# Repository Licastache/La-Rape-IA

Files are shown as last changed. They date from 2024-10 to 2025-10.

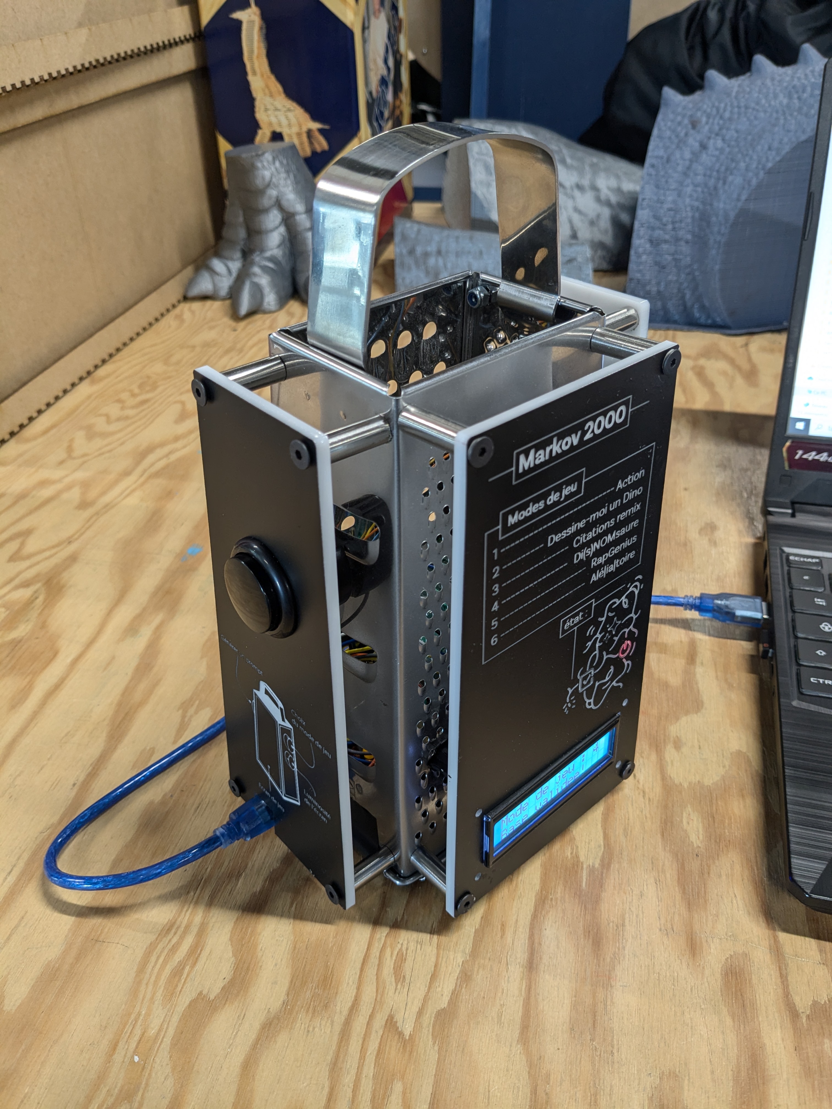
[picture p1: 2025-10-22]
Photos pour git/PXL_20241113_132945148.jpg

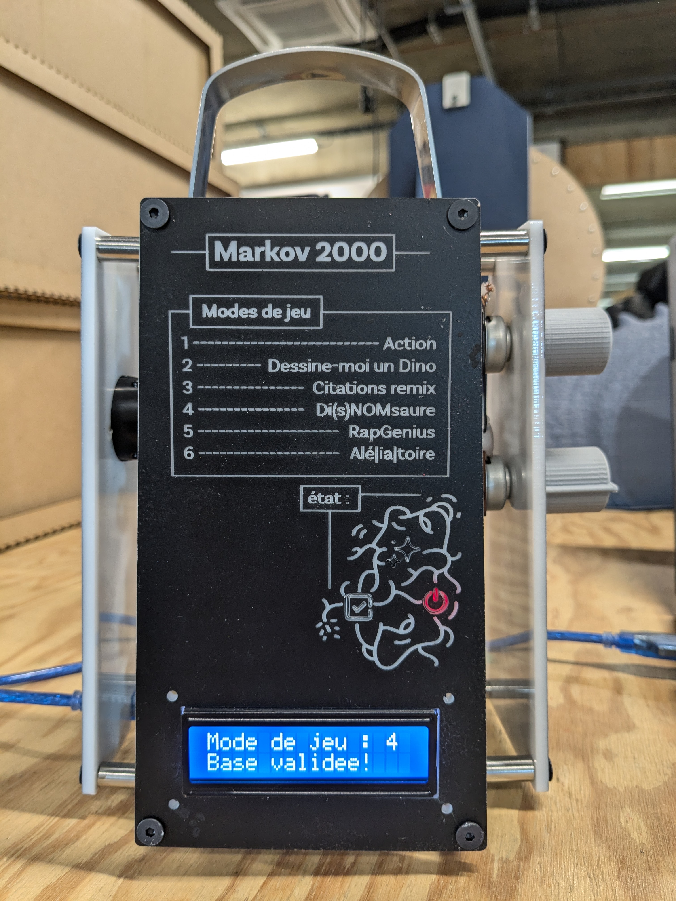
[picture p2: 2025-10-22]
Photos pour git/PXL_20241113_132952643.jpg

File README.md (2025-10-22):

Bienvenue au tutoriel du fonctionnement de la râpe IA Markov 2000 ! 

Informations importantes : 

- 1 : ce projet est une réinterprétation du projet "Trouble Maker" de @liangyq404 :

- 2 : Ce README n'est pas encore tout à fait à jour. Nous conseillons au lecteur de faire attention à l'étape de configuration de l'ordinateur (dans l'étape 3), qui est issue de la première contribution de @VianneyDubourg, avant la mise à jour du code de @nopalpite et l'intégration dans le raspberry pi à la place de l'ordinateur

https://github.com/liangyq404/trouble_maker

https://yibo-fu.com/TroubleMaker

Pour commencer, nous allons parler de la fabrication de la râpe. Ensuite, nous verrons comment préparer et contrôler l'ordinateur et, pour finir, je vous montrerai comment la faire fonctionner.  

Matériel nécessaire  

Avant de commencer, voici la liste du matériel dont vous aurez besoin pour créer une râpe Markov 2000 fonctionnelle :  

- 1 fer à souder à l’étain pour les brasures  
- 1 bobine d’étain  
- 1 kit de jumpers Arduino (mâle-femelle et mâle-mâle)  
- 1 bouton de borne d’arcade  
- 2 potentiomètres compatibles Arduino  
- 1 écran bleu à cristaux liquides sans I2C  
- 1 râpe à fromage  
- 1 imprimante 3D  
- 1 découpeuse laser  
- 12 boulons et écrous M3x30  
- 1 plaque de plexiglas blanc de 4 mm (50x80 cm)  
- 1 bombe de peinture acrylique mate noire  
- 1 tube en acier de 5 mm de diamètre intérieur
- 1 raspberry pi

---

ÉTAPE 1 : Préparer et souder tous les éléments  

IA QUOI LA DEDANS _ (1)

⚠ ATTENTION ! Ne soudez pas encore le bouton et les potentiomètres, car les câbles doivent d'abord passer dans les trous de la râpe.  

---

ÉTAPE 2 : Découpe laser du carénage  

Pour cette étape, nous allons utiliser une découpeuse laser. Prenez votre plaque de PMMA de 4 mm (ou trolase noir/blanc) et lancez la découpe du fichier "Plaque de trolase habillage rape v3.SVG".  

---

ÉTAPE 3 : Assemblage

1. Découpez votre tube en acier de 5 mm en tronçons de 20 mm.  
2. Fixez les plaques sur la râpe (pensez à percer tous les trous nécessaires au préalable).  
3. Utilisez les boulons et écrous M3x30 pour fixer le carénage.  

---
------------  ETAPE A CORRIGER -----------------
Ensuite, nous allons voir comment configurer l'ordinateur.  

Logiciels requis  

Pour commencer, vous devez installer trois logiciels sur votre ordinateur :  

- **Arduino IDE**  
- **VS Code** de Microsoft  
- **Python 3** (version minimale requise) – Téléchargeable sur : [https://www.python.org/](https://www.python.org)  

⚠ **ATTENTION !** Lors de l’installation de Python, assurez vous de bien l’ajouter au **PATH**.

---

Après cela, ajoutez le dossier **TM-SCREEN** sur le bureau de votre ordinateur.  

### **Ouverture du projet dans VS Code**  

1. Ouvrez **VS Code**.  
2. Cliquez sur **Fichier > Ouvrir un dossier** (**File > Open Folder**).  
3. Sélectionnez le dossier **TM-SCREEN**.  

Cela chargera l’ensemble du dossier dans l’onglet de gauche.  

4. Ouvrez le fichier **Python** contenu dans le dossier.  
5. VS Code devrait normalement vous demander d’installer l’extension **Python** sur votre ordinateur. Installez-la si ce n’est pas déjà fait.  

302d3364e0134f43e909c34b77ef948b

---

## **ÉTAPE 4 : Création de la variable d'environnement Python**  

Ensuite, vous devez associer la variable d’environnement disponible dans le fichier **.env** avec le fichier **requirements.txt**.  

---

## **ÉTAPE 5 : Vous pouvez râper des mots** 🧀💻

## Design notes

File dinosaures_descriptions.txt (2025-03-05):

Prédateur redoutable, il mesurait 12 mètres et pesait 9 tonnes.
Carnivore agile, rapide et intelligent, avec des griffes acérées.
Herbivore géant, au long cou, se nourrissant de feuillage élevé.
Herbivore cornu, doté de trois cornes pour se défendre.
Dinosaure à plaques, avec un dos orné et une queue pointue.
Armure vivante, possédant une queue-massue défensive.
Crête osseuse distinctive, utilisée pour la communication.
Vol majestueux, envergure de 7 mètres, chasseur aérien de poissons.
Prédateur bipède, 9 mètres de long, dents tranchantes et griffes acérées.
Herbivore immense, 27 mètres, mangeant les feuilles des arbres.
Prédateur à griffes, rapide et agile pour chasser efficacement.
Herbivore blindé, protégé par une carapace de plaques osseuses.
Chasseur furtif, petit, rapide et précis dans ses attaques.
Géant des airs, plane sur de longues distances en quête de nourriture.
Roi des mers, prédateur marin dominant avec des dents acérées.
Dinosaure à cornes, armes naturelles pour défense et domination.
Dinosaure à bec, adapté à la chasse avec un bec puissant.
Marcheur des marécages, se nourrissant de plantes aquatiques.
Chercheur de trésors, fouille le sol avec ses longues griffes.
Géant des forêts, avancée lente à travers la végétation dense.
Grand bipède carnivore, bras courts, dents acérées, du Crétacé supérieur.
Herbivore massif, long cou et queue, vivait au Jurassique.
Herbivore cornu, collerette osseuse, trois cornes, du Crétacé tardif.
Petit chasseur bipède, griffe en faucille, rapide et agile.
Herbivore blindé, plaques osseuses et queue défensive.
Prédateur à voile dorsale, grand chasseur du Crétacé inférieur.
Dinosaure bipède à plumes, entre dinosaures et oiseaux.
Herbivore à dôme crânien, structure osseuse pour protection.
Herbivore bipède, crête creuse servant à la communication.
Herbivore quadrupède, queue défensive couverte de pointes.
Carnivore à longues griffes, tête petite, du Crétacé supérieur.
Quadrupède massif, peau épaisse, protégé par de petites épines.
Crête osseuse imposante, pour intimider ou séduire.
Petit bipède omnivore, rapide, au bec tranchant.
Quadrupède blindé, plaques osseuses et épines défensives.
Carnivore à museau fin et dents acérées.
Herbivore bipède, bec corné, crête denteleuse sur le dos.
Dinosaure à plumes, ailes rudimentaires, proche des oiseaux.
Quadrupède géant, queue en massue pour se défendre.
Carnivore bipède, crête osseuse pour combat territorial.
Herbivore blindé, plaques osseuses et queue pointue.
Carnivore bipède, tête massive, dents tranchantes, redoutable prédateur.
Herbivore géant, long cou et pattes robustes.
Bipède carnivore, griffes acérées, queue robuste pour l’équilibre.
Herbivore blindé, longues épines dorsales, thermorégulation.
Carnivore bipède, dents tranchantes et museau allongé.
Herbivore bipède, bec puissant et crêtes osseuses.
Dinosaure bipède, plumes, griffes acérées, lien vers les oiseaux.
Herbivore quadrupède, collerette osseuse et cornes frontales.
Carnivore bipède, crête creuse, queue longue et agile.

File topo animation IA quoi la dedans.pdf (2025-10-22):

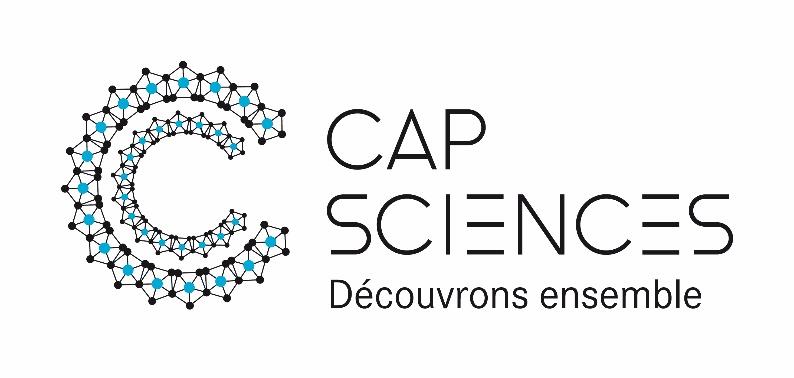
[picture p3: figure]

Fab Lab – Format 1H | Atelier Découverte

# IA quoi là-dedans ?

# Fab Lab

# Format 1H30

Généralités :

- 16 participants
- A partir de 12 ans (5ème)
- 1h30 d’activité
- Montage : 30 min
- Démontage : 30 min

Matériel :

- 3 trouble maker assemblés
- 3 trouble maker éclatés (dans les boites en carton)
- 3 mousses plastazotes
- 3 raspberry pi
- 1 ordinateur diaporama
- 1 clé USB contenant le diaporama
- 3 jeux de cartes composants
- 16 ardoises et crayons d’ardoise
- 1 sac/boite contenant des cartes phrases
- 1 boite à pixels

### Résumé :

Cet atelier se déroule en 1h30.

### Installation :

Former trois îlots pouvant accueillir 5 personnes chacun. Placer un Trouble Maker fonctionnel sur chacun d’eux. Des gommettes sur les PC et râpes permettent d’identifier

Brancher le trouble maker sur le raspberry pi et le disposer au centre de la table.

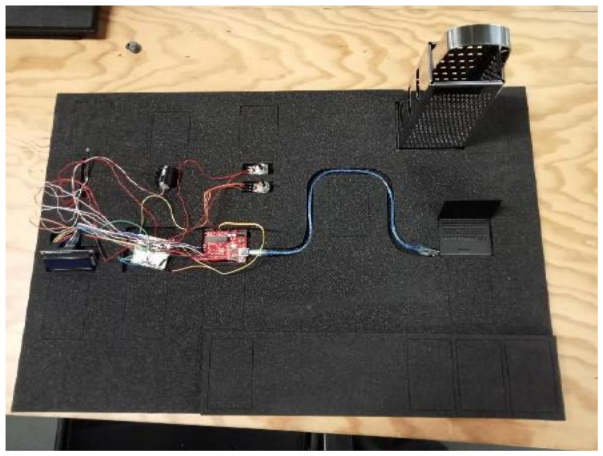
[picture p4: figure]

Disposer les composants des éclatés dans les mousses et mettre le tout de côté.

Mettre de côté les jeux de Memory, les phrases, le cadavre exquis et les ardoises.

Ouvrir le diapo IA quoi la dedans.

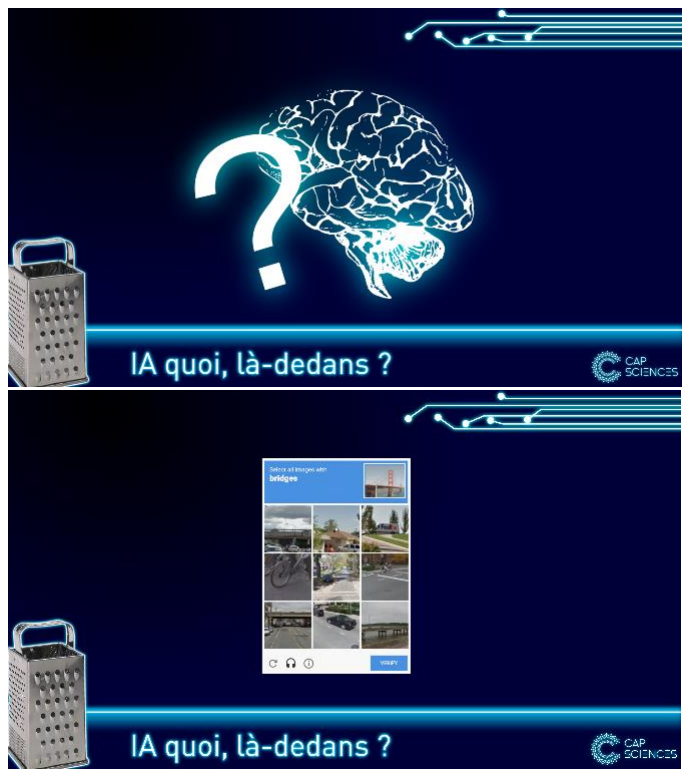
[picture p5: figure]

## Déroulé détaillé :

### 1ère Partie : Découverte du Trouble Maker // 20 minutes

Après s’être présentée et avoir fait connaissance avec les participants, l’animatrice explique :

Avant de débuter, je dois juste vérifier que vous êtes bien des humains. C’est la procédure.

Elle affiche les deux démos du ReCAPTCHA qui sont dans le diapo.

Très bien, pouvez-vous me dire où se trouvent les passages piétons ? Les vélos ? Super, merci beaucoup, on peut continuer.

L’animatrice explique alors aux participants le but de l’atelier : comprendre ce qu’est l’objet qu’ils ont devant eux, ce qu’il y a à l’intérieur et comment il fonctionne.

La première étape est donc de laisser les groupes manipuler l’objet sans leur donner d’instructions. Après 5 minutes, on peut récupérer l’attention de tout le groupe et enchaîner.

Est-ce que vous avez compris ce que fait cet objet ? Pouvez-vous me l’expliquer en quelques phrases ?

A la fin de cette séquence, les participants doivent avoir compris qu’on peut choisir un mode de fonctionnement, et que lorsqu’on appuie sur le gros bouton, cela génère une phrase liée au mode.

L’animatrice demande ensuite si les participants peuvent citer les différents composants de l’objet ainsi que ce à quoi ils servent. Afin de mieux voir, elle apporte un éclaté par groupe et leur donne les cartes composants. Ils peuvent disposer les cartes à côté de chaque composant.

Elle leur demande ensuite de résumer ce que font les différentes parties et apporte la correction si besoin.

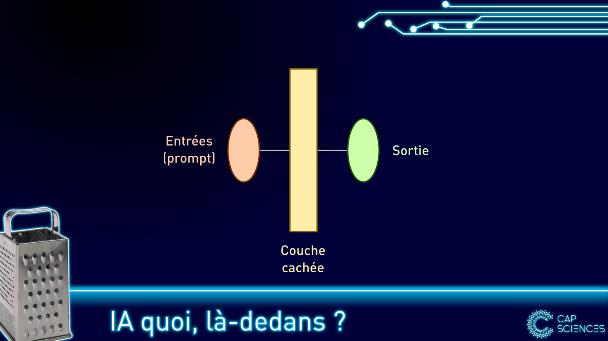
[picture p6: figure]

2

### ème partie : Dans le cerveau de la machine

On sait comment ça fonctionne physiquement ; maintenant on va voir comment ça fonctionne en terme de programmation.

Cette machine ressemble un peu à ChatGPT, Copilot et autres. Elle génère du texte. Comment ? Vous tapez une commande (votre prompt), puis la machine fait quelque chose (on ne sait pas quoi) et vous avez un résultat en sortie. Mettez le Trouble Maker en position Alé(IA)toire et faites-moi sortir une phrase.

Qu’est ce qui sort ? Est-ce que c’est compréhensible ?

Je vais vous donner un papier et j’aimerais que vous me disiez si ça vous permet de comprendre ce que fait la machine.

L’animatrice donne alors la base de données en version papier, ou affiche la base de données sur l’ordinateur du groupe. La réponse attendue est que la machine imprime une phrase composée de blocs pris parmi la liste. Cette liste est une base de données, c’est-à-dire un conteneur qui permet de stocker des données (une liste de noms, de numéros de téléphone, de recettes, etc).

La machine est, entre guillemets, « créative » et afin d‘éviter le temps pris pour générer une quinzaine de phrases, l’animatrice place la Boîte à phrases au centre de la pièce.

Vous allez tous venir piocher une phrase dans cette boite. On va les lire à voix haute et se placer dans d’un côté de la pièce si on estime que la phrase est correcte, et de l’autre si on estime que la phrase est incorrecte.

Les participants s’exécutent et l’animatrice demandent à ceux qui se placent côté incorrect, pourquoi ils estiment leur phrase fausse.

Elle propose ensuite de comprendre comment Trouble Maker construit ses phrases. On lui a appris qu’une phrase commence par une majuscule, se termine par un point, mais on ne lui a pas appris ce qu’est un nom, une action, un lieu ou un objet. Le Trouble Maker se débrouille pour prédire le prochain mot selon une logique qu’on va essayer d’appréhender.

Les participants prennent une ardoise chacun et, par petits groupes, vont noter sans regarder ce que font les autres :

- Le premier : un nom (Dingo, Mon parrain, Un oreiller, Sélim…)
- Le deuxième : une action (se tient, déclare un poème, épluche, est posé…)
- Le troisième : un lieu (à la piscine, chez mamie Monique, dehors…)
- Le quatrième : un objet précédé par « avec » (avec un chou, avec une épée, avec un origami…)
- Le cinquième une date (demain, le 30 février, il y a très longtemps…)

La phrase finale est ensuite lue dans son intégralité. On constate qu’elle est largement insensée. La question peut alors être posée :

Comment peut-on améliorer ce processus ?

Plusieurs réponses peuvent être apportées par les jeunes. Celle qui nous intéresse est la suivante : savoir ce qui a été écrit auparavant.

On peut donc recommencer l’exercice en intégrant ce paramètre. La base de donnée sera nos connaissances à nous, êtres humains, et avant d’écrire notre mot, on peut regarder le mot écrit par la personne avant nous. A la fin de la séquence, récupérer les ardoises en crayons.

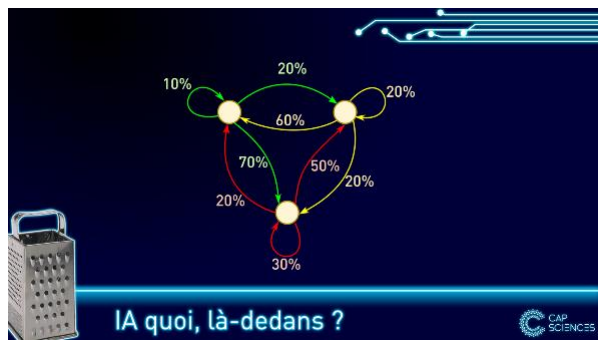
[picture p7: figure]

Ce que nous venons de faire, à quoi est-ce que ça ressemble ? A la prédiction automatique de notre téléphone, exactement ! Eh bien nous venons de recréer un modèle de langage : une chaine de Markov.
C’est un processus dont l’évolution future ne dépend que de la situation présente.

Exemple : si, quand je suis dans ce coin de la pièce, j’ai 1 chance sur 3 d’aller dans le coin à ma droite et 2 chances sur 3 d’aller dans le coin à ma gauche, savoir comment je suis arrivé dans ce coin n’aura aucune incidence sur le choix de l’endroit où je vais aller.

Bien s’assurer que ce processus est compris par l’assemblée. Leur demander de réexpliquer au besoin.

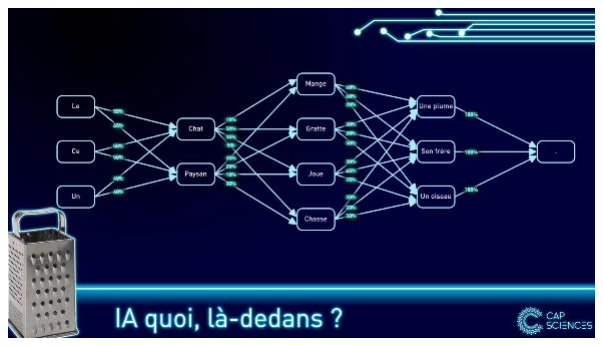
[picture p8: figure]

Pour nos phrases, c’est pareil : Markov utilise le mot actuel pour choisir le mot suivant. Pour cela, il utilise des probabilités.

L’animatrice demande aux participants s’ils savent comment ces probabilités sont établies. La réponse est « grâce aux textes qui ont été utilisés pour entraîner l’IA ».

La chaîne de Markov utilisée avec des séquences de mots est un modèle de langage. Il y en a d’autres, et ils ont tous en commun le fait de prédire le mot suivant dans une séquence de mots.

L’animatrice redonne les ardoises (et les récupère une fois la séquence finie).

Nous avons généré des phrases en regardant le mot de notre prédécesseur, maintenant, nous allons regarder ce qu’ont écrit les deux personnes avant nous pour écrire notre unité. Puis nous feront la même chose mais en regardant ce que tout le monde a écrit.

Si on reprend notre diapo précédente, on a vu que dans la couche cachée, il y a différentes parties qui

Vous avez joué le rôle de la couche cachée en suivant un algorithme, c’est-à-dire une suite d’instructions. Une recette de cuisine, par exemple, c’est un algorithme.
Ce que l’on trouve dans la couche cachée, ce sont souvent ce qu’on appelle des réseaux de neurones. Chaque neurone est entraîné à faire une chose en particulier.

Ce modèle que je vous ai montré est très simple, mais il en existe évidemment de plus compliqués. (Slide avec réseau de neurones plus complexe). Celui, par exemple, est là encore simple. ChatGPT 3 possède des millions de neurones, avec un total de 175 milliards de connexions. A chaque fois qu’on fait une demande à ChatGPT, il va effectuer un calcul impliquant TOUS ces liens. Ça va lui demander un peu d’énergie.

L’animatrice distribue une feuille de papier « consommation maison » à chaque participant et leur explique : cette quantité de papier, ça représente la quantité d’énergie utilisée pour chauffer une maison pendant une journée. Elle demande ensuite combien de ces feuilles ils doivent poser sur la table pour faire fonctionner ChatGPT pendant une journée. Après qu’ils ont fait leurs tentatives, l’animatrice prend une ramette de 500 pages (12 ans de consommation d’une maison) au centre de la table. BAM.

### Ouverture vers les autres IA génératives

On va jouer à Midjourney. Vous connaissez ? Au centre de la table, vous avez des morceaux d’images. Elles vont vous servir à dessiner votre propre mosaïque, en groupe.

Placez le sélecteur de mode de jeu du Trouble Maker sur Description dinosaure. Il vous donnera la description d’un dinosaure inventé. A vous de créer une image qui représente ce dinosaure !

Une fois le dessin fait, l’animatrice prend en photo la création de chaque groupe et peut demander qui est propriétaire du dessin. Les élèves ? Les artistes d’origine ? L’animatrice qui met à disposition le matériel nécessaire à la création de ce dessin ?

### Conclusion

Conclure en demandant leur avis aux participants sur les grands modèles de langage. Ouvrir sur les autres types d’intelligences artificielles qui peuvent exister.

### Notions et définitions

Intelligence artificielle : programme informatique capable d’effectuer des fonctions typiques de la cognition (reconnaitre, décider, prédire, analyser, recommander… Plus récemment, fonctions exécutives : planifier, raisonner, créativité)

Modèle : représentation idéalisée de la réalité ; il permet de faire des hypothèses sur les processus qu’il étudie

Modèle de langage : modèle qui permet de prédire le mot suivant dans une séquence de mots

### Problèmes et solutions

Relancer le programme python :
Il faut l’arrêter d’abord. Cliquer dans le terminal -> Ctrl + C pour arrêter le programme

Le port COM n’est pas le bon :
Vérifier à l’aide des gommettes que la bonne râpe est connectée au bon port USB.
S’il y a quand même un problème, aller dans le gestionnaire de périphérique, chercher dans les ports COM celui qui est relié à l’arduino. Dans le début du code Python, à la ligne 8, changer le numéro du port par celui trouvé dans le gestionnaire de périphérique.

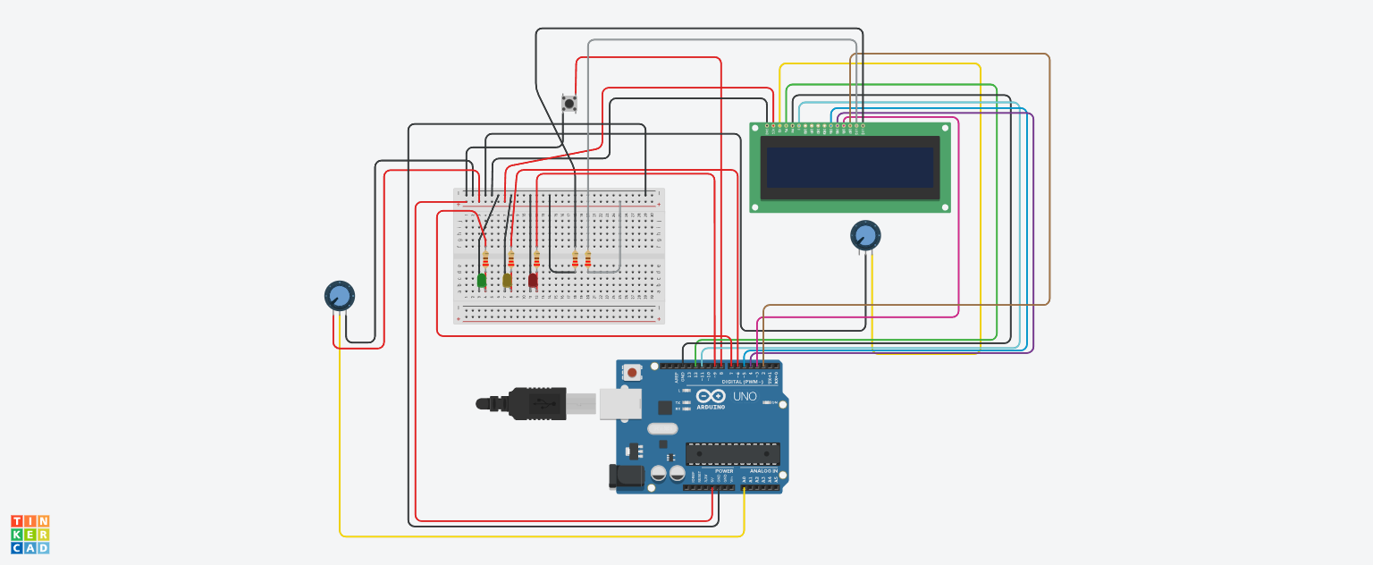
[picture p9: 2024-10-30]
SCHEMA_BOARD.png

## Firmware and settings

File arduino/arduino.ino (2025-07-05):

#include <LiquidCrystal.h>
#include <Bounce2.h>

// Initialisation de l'écran LCD
LiquidCrystal lcd(12, 11, 5, 4, 3, 2);

// Broches
const int potentiometerPin = A0;
const int buttonPin = 8;
const int ledRouge = 9;
const int ledVerte = 7;
const int ledOrange = 6;

Bounce debouncer = Bounce();

int currentBase = 0;
int lastBase = -1;
bool selectionValidee = false;

void setup() {
  Serial.begin(9600);
  lcd.begin(16, 2);

  pinMode(ledRouge, OUTPUT);
  pinMode(ledVerte, OUTPUT);
  pinMode(ledOrange, OUTPUT);
  digitalWrite(ledRouge, HIGH);
  digitalWrite(ledOrange, LOW);
  digitalWrite(ledVerte, LOW);

  debouncer.attach(buttonPin, INPUT_PULLUP);
  debouncer.interval(25);
}

void loop() {
  debouncer.update();

  int sensorValue = analogRead(potentiometerPin);
  sensorValue = constrain(sensorValue, 0, 1022);
  currentBase = map(sensorValue, 0, 1023, 0, 6);

  if (!selectionValidee) {
    if (currentBase != lastBase) {
      lcd.setCursor(0, 0);
      lcd.print("Mode de jeu :    ");
      lcd.setCursor(13, 0);
      lcd.print(currentBase + 1);
      lastBase = currentBase;
    }

    if (debouncer.fell()) {
      selectionValidee = true;
      lcd.setCursor(0, 1);
      lcd.print("                ");  // Effacer la ligne avant affichage
      lcd.setCursor(0, 1);
      lcd.print("Base validee!");

      digitalWrite(ledRouge, LOW);
      digitalWrite(ledVerte, HIGH);
      delay(300);
      digitalWrite(ledVerte, LOW);
      digitalWrite(ledRouge, HIGH);

      Serial.println(currentBase);
      Serial.println("READY");
    }
  }

  if (selectionValidee && Serial.available() > 0) {
    String receivedText = "";
    digitalWrite(ledRouge, LOW);
    digitalWrite(ledOrange, HIGH);  // LED orange allumée pendant traitement

    while (Serial.available() > 0) {
      char c = Serial.read();
      // Ne garder que les caractères imprimables ASCII (32 à 126)
      if (c >= 32 && c <= 126) {
        receivedText += c;
      }
      delay(2);
    }

    Serial.print("DEBUG RX: [");
    Serial.print(receivedText);
    Serial.println("]");

    lcd.clear();
    scrollText(receivedText);

    Serial.println("DONE");
    selectionValidee = false;
    digitalWrite(ledOrange, LOW);  // Extinction LED orange
    digitalWrite(ledRouge, HIGH);
    lastBase = -1;
  }
}

void scrollText(String text) {
  String scrollingText = "                " + text + "                ";
  int textLength = scrollingText.length();

  for (int i = 0; i <= textLength - 16; i++) {
    lcd.setCursor(0, 1);
    lcd.print(scrollingText.substring(i, i + 16));
    delay(300);
  }
}

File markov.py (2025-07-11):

import serial
import time
import markovify
import sys
import unicodedata
import re
import glob

BAUD_RATE = 9600
TIMEOUT = 60  # Timeout de lecture série en secondes

bases_de_donnees = [
    "actions_verites.txt",
    "dinosaures_descriptions.txt",
    "citations_celebres.txt",
    "dinosaures_noms.txt",
    "rap.txt",
    "aleatoire.txt"
]

def retirer_accents(texte):
    texte_normalise = unicodedata.normalize('NFD', texte)
    return ''.join(c for c in texte_normalise if unicodedata.category(c) != 'Mn')

def charger_donnees(chemin):
    try:
        with open(chemin, "r", encoding="utf-8") as f:
            return f.read()
    except Exception as e:
        print(f"[ERREUR] Lecture fichier {chemin} : {e}")
        return ""

def generer_phrase(texte):
    if not texte.strip():
        return None
    try:
        modele = markovify.Text(texte)
        for _ in range(5):
            phrase = modele.make_sentence()
            if phrase:
                return ' '.join(phrase.split())
    except Exception as e:
        print(f"[ERREUR] Génération Markov : {e}")
    return None

def attendre_message(ser, attendu, timeout=TIMEOUT):
    print(f"[INFO] Attente de '{attendu}'")
    t0 = time.time()
    while time.time() - t0 < timeout:
        if ser.in_waiting > 0:
            ligne = ser.readline().decode('utf-8').strip()
            print(f"[←] {ligne}")
            if ligne == attendu:
                return True
        time.sleep(0.05)
    print(f"[ERREUR] Timeout : pas de '{attendu}' reçu.")
    return False

def detecter_port_serie():
    ports_possibles = glob.glob("/dev/ttyACM*") + glob.glob("/dev/ttyUSB*")
    if not ports_possibles:
        print("[ERREUR] Aucun port série détecté (ttyACM* ou ttyUSB*).")
        return None
    print(f"[INFO] Port série détecté : {ports_possibles[0]}")
    return ports_possibles[0]

def main():
    port_serie = detecter_port_serie()
    if port_serie is None:
        sys.exit(1)

    try:
        ser = serial.Serial(port_serie, BAUD_RATE, timeout=1)
        ser.flush()
        print("[OK] Connexion série établie.")
    except serial.SerialException as e:
        print(f"[ERREUR] Port série : {e}")
        sys.exit(1)

    try:
        while True:
            if ser.in_waiting > 0:
                ligne = ser.readline().decode('utf-8').strip()
                if ligne.isdigit():
                    base_index = int(ligne)
                    if base_index < 0 or base_index >= len(bases_de_donnees):
                        print(f"[ERREUR] Index {base_index} invalide.")
                        continue

                    print(f"[→] Index reçu : {base_index}")

                    if attendre_message(ser, "READY"):
                        texte = charger_donnees(bases_de_donnees[base_index])
                        phrase = generer_phrase(texte)
                        
                        if phrase:
                            phrase = retirer_accents(phrase)
                            print(f"[→] Phrase envoyée : {phrase}")
                            ser.write((phrase + "\n").encode('utf-8'))

                            if attendre_message(ser, "DONE"):
                                print("[✓] Phrase affichée.")
                        else:
                            print("[ERREUR] Aucune phrase générée.")
                    else:
                        print("[ERREUR] Pas de READY reçu, on ignore cette demande.")
                else:
                    print(f"[WARN] Donnée inattendue : {ligne}")
            time.sleep(0.1)

    except KeyboardInterrupt:
        print("\n[INFO] Arrêté par l'utilisateur.")
    finally:
        ser.close()
        print("[INFO] Port série fermé.")

if __name__ == "__main__":
    main()

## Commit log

2025-07-04 move arduino sketch inside arduino folder
2025-07-04 fix valeur 7 sur potentiometre
    [arduino.ino]
2025-07-11 change serial port for raspberry
2025-07-11 add serial port name detection for raspberry
2025-10-22 Ajout des fichiers nécessaires à l'animation
    Topo : contenu du scénario d'animation
    Productions Découpe LASER : pour produire les accessoires de manipulations et de jeux de l'atelier (hors rape)
    Plaque de trolase habillage rape v3 : carénage à découper dans du trolase ou pmma
    Diapo déroulé : à projeter lors de l'animation
2025-10-22 Ajout de photos de l'objet et cartes de l'éclaté
